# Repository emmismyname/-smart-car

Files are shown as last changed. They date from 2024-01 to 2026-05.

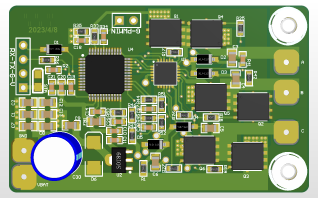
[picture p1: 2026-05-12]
hardware/ESC_Brushless_V4.12.png

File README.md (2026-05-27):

# Smart Car Project (Electromagnetic)

A high-speed intelligent vehicle based on the **STC32G** microcontroller, designed for electromagnetic field tracking competitions.

## 🚗 Overview
This project features an autonomous car that detects alternating magnetic fields from a track. It utilizes PID control for steering and speed management.

* **MCU**: STC32G12K128 (8051 Architecture)
* **Tools**: Altium Designer (Hardware), Keil uVision5 (Software)
* **Key Features**: Inductive sensing, PID control, Brushless ESC support.

---

## 🛠️ Hardware Design
The hardware files are located in the `/hardware` directory.

### 1. Driver Board
Handles signal processing from induction coils and controls the motors.

### 2. Power Module
Regulates 2S/3S LiPo battery input to stable 5V and 3.3V rails.



---

## 📂 Repository Structure
* `hardware/`: Altium Designer schematics and PCB layouts.
* `USER/`: Core application logic and interrupt handlers.
* `Libraries/`: Seekfree STC32 open-source library and drivers.
* `Docs/`: Pinout maps and sensor calibration data.

---

## 🚀 Getting Started
1.  **Hardware**: Open `.PcbDoc` files in Altium Designer to view layouts or generate Gerber files for manufacturing.
2.  **Software**:
    * Open the project in **Keil5**.
    * Compile and flash the firmware via STC-ISP.
    * Monitor sensor values using the serial debugger.

---

## 📈 Project Status
- [x] Power module design & testing
- [x] Driver board PCB layout
- [ ] PID algorithm optimization for high-speed cornering
- [ ] Integration of Brushless ESC

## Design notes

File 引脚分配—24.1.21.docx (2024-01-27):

一、主板 STC32F（核心板）

1、 主板运放通信 HS_SPI_2：

P25 SCLK_2 时钟信号

P24 MISO_2 从主传输

P23 MOSI_2 主从传输

P22 SS_2 片选信号

2、主板遥控板通信 UART_2：

P10 RxD2 串口接收端

P11 TxD2 串口发送端

2、 IMU姿态 HS_SPI_4：

P32 SCLK_4时钟信号

P33 MISO_4从主传输

P34 MOSI_4 主从传输

P35 SS_4 片选信号

4、无线串口UART_4：

P02 RxD4 串口发送端

P03 TxD4 串口接收端

P07 IO 无线串口RST

P45 IO 无线串口NC（悬空）

5、编码器1 T3：

P04 T3 定时器外部输入

P53 IO 编码器方向

6、编码器2 T4：

P06 T4 定时器外部输入

P00 IO 编码器方向

7、电池电压 ADC5：

P15 ADC4 模数转换

8、霍尔传感器 INT3：

P37 INT3 外部中断

9、电机信号 PWM：

P13 PWM2 PWM波形输出

P26 PWM4 PWM波形输出

P01 IO 电机方向

P05 IO 电机方向

10、蜂鸣器 IO：

P14 IO 蜂鸣器

11、按键 IO：

P50、P51、P16

12、复位 RST

P54 RST 复位键

（PCB Layout时为了连线方便GPIO可跟换连接引脚）

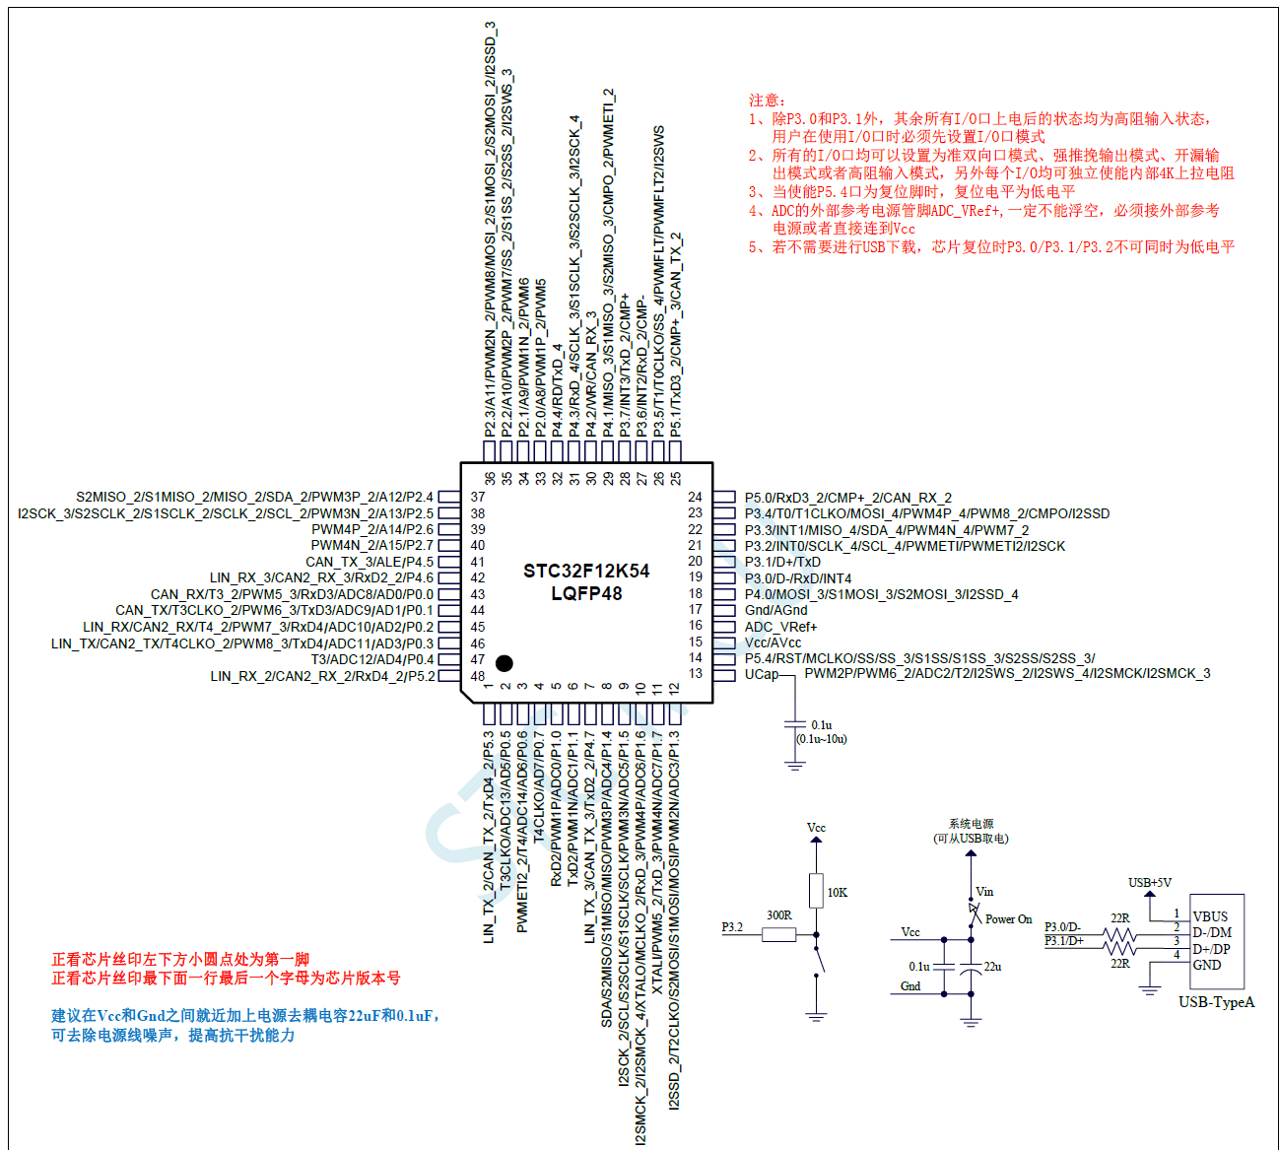
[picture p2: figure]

二、运放板 STC32F（贴片）

1.运放主板通信 HS_SPI_2：

P25 SCLK_2 时钟信号

P24 MISO_2 从主传输

P23 MOSI_2 主从传输

P22 SS_2 片选信号

2.TOF测距 模拟IIC：

P37 INT4 外部中断

P36 IO 使能引脚

P46 IO 模拟I2C_SDA

P47 IO 模拟I2C_SCL

3.运放 ADC：

P13--17 —>ADC3-7（5）

P00--06 —>ADC8-14（7）

4.烧录 ：

P30 D- 烧录接收端

P31 D+ 烧录发送端

5.复位：

P54 RST复位键

三、遥控板 STC32G（核心板）

1.遥控主板通信 UART_2：

P10 RxD2 串口接收端

P11 TxD2 串口发送端

2.OLED显示屏 SPI_2：

P25 SCLK_2 时钟信号

P24 MISO_2 从主传输

P23 MOSI_2 主从传输

P22 SS_2 片选信号

3.按键 IO（连线从简，布局优先）：

0-9数字按键（10P）

确认、返回（2P）

退格（1P）

点号（1P）

拨码（2P）

五向按键（5P）

4.复位：

P54 RST复位键

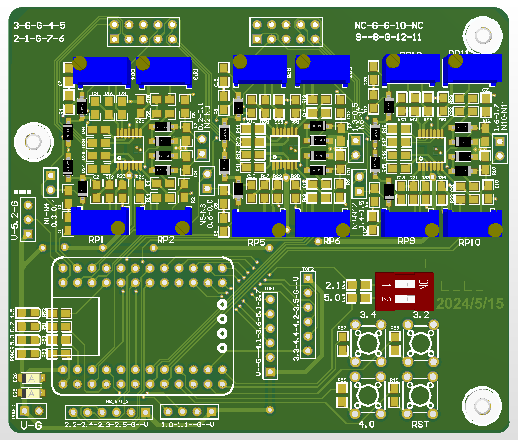
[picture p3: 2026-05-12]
hardware/12·channel amplifier.png

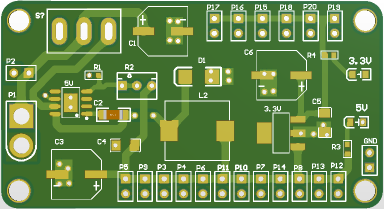
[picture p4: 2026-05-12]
hardware/Power_Module.png

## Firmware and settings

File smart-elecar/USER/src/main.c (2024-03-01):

/*********************************************************************************************************************
 * COPYRIGHT NOTICE
 * Copyright (c) 2020,逐飞科技
 * All rights reserved.
 * 技术讨论QQ群：一群：179029047(已满)  二群：244861897(已满)  三群：824575535
 *
 * 以下所有内容版权均属逐飞科技所有，未经允许不得用于商业用途，
 * 欢迎各位使用并传播本程序，修改内容时必须保留逐飞科技的版权声明。
 *
 * @file       		main
 * @company	   		成都逐飞科技有限公司
 * @author     		逐飞科技(QQ790875685)
 * @version    		查看doc内version文件 版本说明
 * @Software 		MDK FOR C251 V5.60
 * @Target core		STC32G12K128
 * @Taobao   		https://seekfree.taobao.com/
 * @date       		2020-12-18
 ********************************************************************************************************************/

#include "headfile.h"
#include "allcodeinr.h"

/*********************************************函数声明*********************************************************/

/********************************初始化操作函数**********/
void initall_PID();			// PID结构体内误差清理
void arangement_init(); // 初始化设定
void parameter_init();	// 初始化设定
/***************************************************************************************************/

/********************************运动模式操作函数**********/

void Hall_detection(); // 霍尔检测
void TOF_detection();	 // 红外检测
void left_infrared();	 // 左红外避障
void right_infrared(); // 右红外避障

/***************************************************************************************************/

/********************************电机输出和电磁电压检测操作函数**********/
void ADC_battery_quire(); // 获取电池的电压数值
/***************************************************************************************************/

/********************************显示屏操作函数**********/
void system_display(); // 根据按键反馈对应界面
/***************************************************************************************************/

/********************************电感函数**********/
void Element_Idef(); // 元素识别
/**************************************************/

/********************************PID相关函数**********/
void PID_all_set();
/****************************************************/
void start_dection(); // 发车检测
void stop_dection();	// 停车检测
/*
 * 系统频率，可查看board.h中的 FOSC 宏定义修改。
 * board.h文件中FOSC的值设置为0,则程序自动设置系统频率为33.1776MHZ
 * 在board_init中,已经将P54引脚设置为复位
 * 如果需要使用P54引脚,可以在board.c文件中的board_init()函数中删除SET_P54_RESRT即可
 */

void main()
{
	arangement_init(); // 初始化设定
	parameter_init();	 // 参数初始化
	while (1)
	{
		if (gyro_flag)
		{
			MPU_Acquire();
		}
		wireless_read(1);						 // 无线转串口入出
		system_display();						 // 显示界面
		Button_Scan();							 // 按钮扫描
		resetelec_Init();						 // 电感最大最小值检测
		wireless_send(uart_mode, 5); // 无线转串口输出
		start_dection();						 // 发车检测
		stop_dection();							 // 停车检测
	}
}

void start_dection() // 发车检测
{
	if (jiangxing_No_1.start_flag == 1)
	{
		switch (jiangxing_No_1.start_mode)
		{
		case 0:
		{
			jiangxing_No_1.stop_flag = 0; // 停车置零
			initall_PID();
			// 初始化读取积分零漂
			motor_flag = 0;
			gyro_flag = 1; //
			yaw_output = 0.0f;
			pitch = 0.0f;
			distance_L = 0;
			distance_R = 0;
			trace_flag=1;
			/////////////////////////////////////////
			// 显示屏开关关闭
			button_switch = 0;
			display_switch = 0;
			// 陀螺仪初始化
			motor_flag = 1;
			Target_speed = base_speed; // 速度控制
			//////////////////////
			jiangxing_No_1.start_flag = 0; // 清除标志位
			///////////////////////////////
		}
		break;
    case 1://距离跑
		{
  


		}
    break;

		default:
			break;
		}
	}
}

void stop_dection() // 停车检测
{
	if (jiangxing_No_1.stop_flag == 1) // 停车标志位为1
	{
		jiangxing_No_1.start_flag = 0; // 发车置零
		motor_flag = 0;
		trace_flag=0;
		jiangxing_No_1.stop_flag = 0;
	}
}

void arangement_init() // 初始化设定
{
	board_init(); // 初始化寄存器,勿删除此句代码。
	// 此处编写用户代码(例如：外设初始化代码等)
	iap_init();					// 初始化EEPROM
	ips114_init();			// 初始化1.1.4寸ips屏幕
	DisableGlobalIRQ(); // 关闭总中断
	sys_clk = 35000000; // 设置系统频率为35MHz
	WTST = 0;						// 设置程序代码等待参数，赋值为0可将CPU执行程序的速度设置为最快
	// sys_clk可选值:30000000, 27000000. 24000000, 22118400, 20000000, 18432000, 12000000, 11059200, 6000000, 5529600。
	// 设置系统频率，此频率需要跟STC-ISP软件中的 <输入用户程序运行的IRC频率>选项的频率一致。
	// 如果频率设置不对，将会导致串口的数据不正常,PWM的工作不正常等等。
	board_init(); // 设置玩主频后再次初始化内部寄存器
	delay_init();
	ips114_init();														// 初始化1.1.4寸ips屏幕
	wireless_uart_init();											// 无线转串口模块初始化
	ctimer_count_init(SPEEDL_PLUSE);					// 初始化定时器0作为外部计数
	ctimer_count_init(SPEEDR_PLUSE);					// 初始化定时器3作为外部计数
	gpio_mode(KEY1_PIN, GPI_IMPEDANCE);				// S1按键引脚模式: 高阻输出
	gpio_mode(KEY2_PIN, GPI_IMPEDANCE);				// S2按键引脚模式: 高阻输出
	gpio_mode(KEY3_PIN, GPI_IMPEDANCE);				// S3按键引脚模式: 高阻输出
	gpio_mode(KEY4_PIN, GPI_IMPEDANCE);				// S4按键引脚模式: 高阻输出
	gpio_mode(HRTRIG, GPI_IMPEDANCE);					// S4按键引脚模式: 高阻输出
	gpio_mode(P6_7, GPO_PP);									// 将P6.7蜂鸣器设置为推挽输出
	BEEP = 0;																	// 蜂鸣器关闭
	pit_timer_ms(TIM_4, 5);										// 使用定时器4做周期中断，时间5ms一次。电机控制
	EnableGlobalIRQ();												// 开启总中断
	adc_init(BAT_VOL_PIN, ADC_SYSclk_DIV_32); // 初始化电压引脚
	initall_PID();														// PID结构体清零
	gpio_mode(P6_4, GPO_PP);									// P64引脚设置为推挽输出
	gpio_mode(P6_0, GPO_PP);									// P60引脚设置为推挽输出
	pwm_init(PWM_1, 17000, 0);								// 初始化PWM1  使用P60引脚  初始化频率为17Khz
	pwm_init(PWM_2, 17000, 0);								// 初始化PWM2  使用P62引脚  初始化频率为17Khz
	adc_init(ADC_P00, 0);											// P00引脚		具体通道与引脚对应关系可以查看zf_adc.h文件	  adc[7].data_0 = adc_mean_filter(ADC_P00,8);		//采集并处理ADC_P16电压，精度12位R1—————(L1)
	adc_init(ADC_P01, 0);											// P01引脚		具体通道与引脚对应关系可以查看zf_adc.h文件	  adc[6].data_0 = adc_mean_filter(ADC_P01,8);		//采集并处理ADC_P14电压，精度12位R2—————(L2)
	adc_init(ADC_P05, 0);											// P05引脚		具体通道与引脚对应关系可以查看zf_adc.h文件	  adc[5].data_0 = adc_mean_filter(ADC_P06,8);		//采集并处理ADC_P06电压，精度12位R3—————(L3)
	adc_init(ADC_P13, 0);											// P13引脚		具体通道与引脚对应关系可以查看zf_adc.h文件		adc[1].data_0 = adc_mean_filter(ADC_P13,8);		//采集并处理ADC_P17电压，精度12位L1—————(L7)
	adc_init(ADC_P14, 0);											// P14引脚		具体通道与引脚对应关系可以查看zf_adc.h文件    adc[2].data_0 = adc_mean_filter(ADC_P14,8);		//采集并处理ADC_P13电压，精度12位L2—————(L6)
	adc_init(ADC_P16, 0);											// P16引脚		具体通道与引脚对应关系可以查看zf_adc.h文件    adc[3].data_0 = adc_mean_filter(ADC_P16,8);		//采集并处理ADC_P01电压，精度12位L3—————(L5)
	adc_init(ADC_P17, 0);											// P17引脚		具体通道与引脚对应关系可以查看zf_adc.h文件	  adc[4].data_0 = adc_mean_filter(ADC_P17,8);		//采集并处理ADC_P05电压，精度12位M-—————(L4)
	adc_init(ADC_P06, 0);											// P06引脚		具体通道与引脚对应关系可以查看zf_adc.h文件
	adc_init(ADC_P10, 0);											// P10引脚
	adc_init(ADC_P11, 0);											// P11引脚
	// 外部中断2，3打开
	exit_init(INT2_P36, FALLING_EDGE);
	exit_init(INT3_P37, FALLING_EDGE);
	// EX2=1;
	// tof initial
	//	while (dl1a_init())
	//	{
	//		delay_ms(500);
	//		printf("VL53L0X init try again.\r\n");
	//	}

	while (MPU_Init())
	{
		printf("STC32 MPU6050 GYRO Init test!  \r\n");
	}
	MPU6050_DMP_Init();
	printf("STC32 MPU6050 DMP test!  \r\n");

	read_all_par(); // 读取eeprom数值
									// Zero_Offset_set(); // mpu6050 DMP上电矫正时间
}

void parameter_init() // 参数初始化
{
	// 后排电感最大值
	adc[1].data_max = 2262;
	adc[2].data_max = 2307;
	adc[3].data_max = 2038;
	adc[4].data_max = 2282;
	adc[5].data_max = 2081;
	// 前排电感最大值
	adc[6].data_max = 2146;
	adc[7].data_max = 2113;
	adc[8].data_max = 2022;
	adc[9].data_max = 2051;
	adc[10].data_max = 2030;
	// 后排电感最小值
	adc[1].data_min = 0;
	adc[2].data_min = 0;
	adc[3].data_min = 0;
	adc[4].data_min = 0;
	adc[5].data_min = 0;
	// 前排电感最小值
	adc[6].data_min = 0;
	adc[7].data_min = 0;
	adc[8].data_min = 0;
	adc[9].data_min = 0;
	adc[10].data_min = 0;
	// ZeroOffset_init(); //yaw数值零飘
	// 显示屏页面设置
	sys_display[1] = 1;
	sys_display[2] = 0;
	sys_display[3] = 0;
	button_switch = 1;	// 按钮开启
	display_switch = 1; // 显示开启
	gyro_flag = 1;			// 开启陀螺仪
	yaw_output = 0.0f;
	// PID结构体清零
	initall_PID();
	// 初始化读取积分零漂
	motor_flag = 0;// 电机软开关关闭

	distance_L = 0; // 左轮里程清0
	distance_R = 0;			// 右轮里程清0

	//////////////////////
	jiangxing_No_1.start_flag = 0; // 清除标志位
	jiangxing_No_1.stop_flag = 1;	 // 清除标志位
	jiangxing_No_1.start_mode = 0; // 发车模式
	base_speed = 120;							 // 速度控制
}

//-------------------------------------------------------------------------------------------------------------------
// @brief		PID结构体内容清理
//
//-------------------------------------------------------------------------------------------------------------------
void initall_PID()
{
	pid_init(&Speed_PID_L);
	pid_init(&Speed_PID_R);
	pid_init(&Swerve_PID);
	pid_init(&Forward_PID);
	pid_init(&Pout_PID);
	pid_init(&Pout_rate_PID);
	pid_init(&roundaboutL_PID);
	pid_init(&roundaboutR_PID);
	pid_init(&climb_PID);
	// pid_init(&fuzzy_PID);
	err = 0;
	err_last = 0;
	err_angle_rate = 0;
}

//-------------------------------------------------------------------------------------------------------------------
//  @brief      按钮获取
//  @param      按键状态
//  @param      拨码状态
//  @return     PID参数调整 显示界面
//-------------------------------------------------------------------------------------------------------------------
void Button_Scan()
{
	// 获取拨码开关状态
	sw1_status = SW1_PIN;
	sw2_status = SW2_PIN;

	// 使用此方法优点在于，不需要使用while(1) 等待，避免处理器资源浪费
	// 保存按键状态
	key1_last_status = key1_status;
	key2_last_status = key2_status;
	key3_last_status = key3_status;
	key4_last_status = key4_status;
	// 读取当前按键状态
	key1_status = KEY1_PIN;
	key2_status = KEY2_PIN;
	key3_status = KEY3_PIN;
	key4_status = KEY4_PIN;

	// 检测到按键按下之后  并放开置位标志位
	if (key1_status && !key1_last_status)
		key1_flag = 1;
	if (key2_status && !key2_last_status)
		key2_flag = 1;
	if (key3_status && !key3_last_status)
		key3_flag = 1;
	if (key4_status && !key4_last_status)
		key4_flag = 1;

	// 标志位置位之后，可以使用标志位执行自己想要做的事件
	if (key1_flag)
	{
		if (sw1_status == 1 && sw2_status == 1)
		{
			cursor = cursor - 1;
			ips114_clear(WHITE);											// 清屏
			ips114_showstr(0, cursor, (uint8 *)"->"); // 光标位置
		}
		///////////////使用按键之后，应该清除标志位
		key1_flag = 0;													// 使用按键之后，应该清除标志位
		if (sw1_status == 0 && sw2_status == 0) // 双拨码开关屏幕
		{
			ips114_clear(WHITE); // 清屏
			display_switch = 0;
			button_switch = 0;
		}
	}
	if (key2_flag)
	{
		if (sw1_status == 1 && sw2_status == 1)
		{
			cursor = cursor + 1;
			ips114_clear(WHITE);											// 清屏
			ips114_showstr(0, cursor, (uint8 *)"->"); // 光标位置
		}
		///////////////使用按键之后，应该清除标志位
		key2_flag = 0;													// 使用按键之后，应该清除标志位
		if (sw1_status == 0 && sw2_status == 0) // 双拨码开关屏幕
		{
			display_switch = 1;
			button_switch = 1;
		}
	}

	if (button_switch == 1) // debug打开按键调参
	{
		if (key3_flag)
		{
			if (sw1_status == 1 && sw2_status == 1) // 光标操作
			{
				if (sys_display[1] == 1)
				{
					sys_display[1] = cursor + 2;
				}
				else if (sys_display[1] != 1)
				{
					sys_display[2] = cursor + 1;
				}
				ips114_clear(WHITE);
				cursor = 0;
				ips114_showstr(0, cursor, (uint8 *)"->"); // 光标位置
			}

			else if ((sw2_status == 0 || sw1_status == 0) && sys_display[1] == 2) // 软件打开电机占控比输出
			{
				switch (cursor)
				{
				case 0:
					jiangxing_No_1.start_flag = 1;
					break;
				case 1:
					resetelec_flag = 0;
					break;
				case 2:
					PID_all_set(); // 设置pid
					break;
				case 3:
				{
					uart_mode = uart_mode + 1;
					if (uart_mode > 10)
						uart_mode = 10;
					else if (uart_mode < 0)
						uart_mode = 0;
				}
				break;
				case 4:
				{
					brusheless_flag = 1;
					brusheless_duty = 630;
					delay_ms(1000);
					trace_flag = 1;
					initall_PID();
				}
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

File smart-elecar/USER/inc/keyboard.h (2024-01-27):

#ifndef _KEY_BOARD_H_
#define _KEY_BOARD_H_

#define KEY1_PIN P73
#define KEY2_PIN P71
#define KEY3_PIN P72
#define KEY4_PIN P70
// 定义拨码开关引脚
#define SW1_PIN P75
#define SW2_PIN P76

#include "common.h"

// 拨码开关状态变量
extern uint8 sw1_status;
extern uint8 sw2_status;

// 开关状态变量
extern uint8 key1_status;
extern uint8 key2_status;
extern uint8 key3_status;
extern uint8 key4_status;

// 上一次开关状态变量
extern uint8 key1_last_status;
extern uint8 key2_last_status;
extern uint8 key3_last_status;
extern uint8 key4_last_status;

// 开关标志位
extern uint8 key1_flag;
extern uint8 key2_flag;
extern uint8 key3_flag;
extern uint8 key4_flag;

extern int button_switch; // 第三和第四个按键的开关，调参开关开关与否

extern void Button_Scan();

#endif

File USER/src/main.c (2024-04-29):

/*********************************************************************************************************************
 * COPYRIGHT NOTICE
 * Copyright (c) 2020,逐飞科技
 * All rights reserved.
 * 技术讨论QQ群：一群：179029047(已满)  二群：244861897(已满)  三群：824575535
 *
 * 以下所有内容版权均属逐飞科技所有，未经允许不得用于商业用途，
 * 欢迎各位使用并传播本程序，修改内容时必须保留逐飞科技的版权声明。
 *
 * @file       		main
 * @company	   		成都逐飞科技有限公司
 * @author     		逐飞科技(QQ790875685)
 * @version    		查看doc内version文件 版本说明
 * @Software 		MDK FOR C251 V5.60
 * @Target core		STC32
 * @Taobao   		https://seekfree.taobao.com/
 * @date       		2023-07-27

 ********************************************************************************************************************/
#include "headfile.h"
#include "mycode.h"


// 关于内核频率的设定，可以查看board.h文件
// 在board_init中,已经将P54引脚设置为复位
// 如果需要使用P54引脚,可以在board.c文件中的board_init()函数中删除SET_P54_RESRT即可


void main()
{ 
		//板载初始化·引脚			
		// 此处编写用户代码 例如外设初始化代码等
		EAXFR=1;//使能访问XFR
		clock_init(SYSTEM_CLOCK_52M);	// 初始化系统频率,勿删除此句代码。
		board_init();					// 初始化寄存器,勿删除此句代码。
		DisableGlobalIRQ(); // 	关闭所有中断

		ctimer_count_init(SPEEDR_PLUSE);					// 初始化定时器4作为外部计数
		ctimer_count_init(SPEEDL_PLUSE);					// 初始化定时器3作为外部计数
		pit_timer_ms(TIM_1, 5);				// 使用定时器4做周期中断，时间4ms一次。电机控制

    LED_init();//led初始化
		WORK_LED_on();//工作灯打开
		Disablespiwork();// 关闭SPI工作内容


		spi_slave_init();							// 初始化SPI(作为从机)		
		wireless_uart_init();				  // 无线转串口模块初始化
	
		motor_init();
		switch_init();                //按键初始化
		iap_init();			            	// 初始化EEPROM
		EnableSPIIRQ();								// 使能SPI中断
		EnableGlobalIRQ();						// 使能总中断


	  pid_all_init();//初始化
		disenablemotor();//关闭电机
		

		while (MPU_Init())
		{
			printf("STC32 MPU6050 GYRO Init test!  \r\n");
		}
		MPU6050_DMP_Init();
		printf("STC32 MPU6050 DMP test!  \r\n");
	  delay_ms(20);//等待定时器获取初始化的时候的编码数值
	  get_switch();//获取初始化时候的拨码状态，用于判断是否要读取eeprom的数值
		
		if(SWITCH3_FLAG==1)
		{
			 car_init(&jiangxing_No_1);//车状态初始化
			 delay_ms(100);
       read_all_par();
			 delay_ms(100);
		}
		else
		{
			  car_init(&jiangxing_No_1);//车状态初始化
				Speed_PID_L.KP=33.0f;
				Speed_PID_L.KI=3.4f;
				Speed_PID_L.KD=0.0f;	
				Speed_PID_R.KP=33.0f;
				Speed_PID_R.KI=3.4f;
				Speed_PID_R.KD=0.0f;
				Forward_PID.KP=-3;
				Forward_PID.KI=-0.01;
				Forward_PID.KD=-40;
				gyro_d=0.01;
		}
   
    Zero_Offset_set();  //处理零飘
		Enablespiwork();   //开启工作
//		enablemotor();//使能电机
	 // 此处编写用户代码 例如外设初始化代码等


    while(1)	
    { 

			MPU_Acquire();			
			wireless_read(1);
			wireless_send(jiangxing_No_1.uart_mode, 5);
		  printf("%d,%d,%d,%d,%d ,%d,%f\n",SWITCH1_FLAG,SWITCH2_FLAG,SWITCH3_FLAG,SWITCH4_FLAG,jiangxing_No_1.uart_mode,uart_mode,Forward_PID.KP);
			printf("%f,%f,%f\n", y_gyro_offset, z_gyro_offset, x_gyro_offset);
        // 此处编写需要循环执行的代码
    }
}

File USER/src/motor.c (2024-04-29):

#include "motor.h"

uint8 brusheless_flag;	// 无刷开关
uint16 brusheless_duty; // 无刷电机数值数值范围在500-1000对应占空比为0%-100%
uint8 motor_flag;

uint8 Dir_L = 1;   // 1左边方向正转  0反转
uint8 Dir_R = 0;   // 0右边方向正转  1反转
uint8 Dir_car = 1; // 正走dir_car=1 L=1 R=0  ;dir_car=0 反走 L=0 R=1

int16 templ_pluse = 0;
int16 tempr_pluse = 0;

float Target_Speed_L = 0; // 左轮目标速度
float Target_Speed_R = 0; // 右轮目标速度

float Current_Speed_L; // 左轮当前速度
float Current_Speed_R; // 右轮当前速度

float duty_L;	  // 左电机pid占空比
float duty_R;	  // 右电机pid占空比
float set_duty_L; // 左电机输出占空比
float set_duty_R; // 右电机输出占空比

int32 distance_L = 0; // 左轮行驶距离
int32 distance_R = 0; // 右轮行驶距离

PID_P Swerve_PID;	   // 转弯差速pid
PID_P Forward_PID;	   // 直行PID控制
PID_P Pout_PID;		   // 陀螺仪PID控制
PID_P Pout_rate_PID; //角速度PID控制
PID_P roundaboutL_PID; // 左环岛pid
PID_P roundaboutR_PID; // 右环岛pid
PID_P Speed_PID_L;	   // 左轮速度pid
PID_P Speed_PID_R;	   // 右轮速度pid
PID_P climb_PID;				//上坡pid
int templ_pluse;	  // 左轮脉冲个数
int tempr_pluse;	  // 右轮脉冲个数
int Target_speed = 0; // 车体目标速度

// float PIDOUT_speed_L;			//左轮速度环的偏差计算结果
// float PIDOUT_speed_R;			//右轮速度环的偏差计算结果

// int32 Target_pluse_L=0;			//左轮目标脉冲数目
// int32 Target_pluse_R=0;			//右轮目标脉冲数目

// int32 Motor_pluse_L;			//左轮速度环的脉冲个数
// int32 Motor_pluse_R;			//左轮速度环的脉冲个数

// float Motor_duty_L=470;			//左电机目标初始占空比用于克服死区电压，电源为满电状态
// float Motor_duty_R=360;			//右电机目标初始占空比用于克服死区电压，电源为满电状态

void get_error(PID_P *pid,float senddata)
{
  pid->err=senddata;
}

void enablemotor()
{
	jiangxing_No_1.motor_flag=1;//电机软件开关
}

void disenablemotor()//电机软件失能
{
	jiangxing_No_1.motor_flag=0;//电机软件开关
}

//-------------------------------------------------------------------------------------------------------------------
//  @brief      pid控制器输出更新内部
//  @param      pid				pid参数
//  @param
//  @return     *pid参数 内部输出结果清零
//-------------------------------------------------------------------------------------------------------------------
void pid_init(PID_P *pid) // PID的误差输出初始化
{
	pid->last_err = 0;
	pid->lastBefore_err = 0;
	pid->err = 0;
	pid->pid_out = 0;
	pid->i_out = 0;
	pid->d_out = 0;
	pid->p_out = 0;
}

//-------------------------------------------------------------------------------------------------------------------
//  @brief    	PID的全部初始化
//  @param      none
//  @param
//  @return     PID的全部初始化
//-------------------------------------------------------------------------------------------------------------------
void pid_all_init() // PID的全部初始化
{
	pid_init(&Speed_PID_L);
	pid_init(&Speed_PID_R);
	pid_init(&Forward_PID);
	pid_init(&Swerve_PID);
	
}

//-------------------------------------------------------------------------------------------------------------------
//  @brief      pid位置式控制器输出
//  @param      pid				pid参数
//  @param      error			pid输入误差
//  @return     PID输出结果
//-------------------------------------------------------------------------------------------------------------------
float PID_Loc_Control(PID_P *pid, float error)
{
	if (error > 5 || error < -5)
	{
		pid->i_out += pid->KI * error;
	} // 位置式PID积分项累加
	else if (error <= 5 || error >= -5)
	{
		pid->i_out = 0;
	}
	pid->p_out = pid->KP * error;
	pid->d_out = pid->KD * (error - pid->last_err);
	pid->pid_out = pid->i_out + pid->p_out + pid->d_out;

	// PID输出限幅
	if (pid->pid_out > (600))
		pid->pid_out = 600;
	if (pid->pid_out < -(600))
		pid->pid_out = -(600);
	// 更新误差,用于下次计算
	pid->last_err = error;
	// 返回PID输出值
	return pid->pid_out;
}

//-------------------------------------------------------------------------------------------------------------------
//  @brief      pid位置式控制器输出
//  @param      pid				pid参数
//  @param      error			pid输入误差
//  @return     PID输出结果
//-------------------------------------------------------------------------------------------------------------------
float PID_Loc_direction_Control(PID_P *pid, float error)
{
	if (pid->err > 4 && pid->err < -4)
	{
		pid->i_out = 0;
	} // 位置式PID积分项累加
	else if (pid->err < 4 && pid->err > -4)
	{
		pid->i_out += pid->KI * error;
	}

	// pid->i_out += pid->KI * error;	   //位置式PID积分项累加

	if (pid->i_out > (100))
		pid->i_out = 100;
	if (pid->i_out < -(100))
		pid->i_out = -(100);
	pid->p_out = pid->KP * error;
	pid->d_out = pid->KD * (error - pid->last_err);
	pid->pid_out = pid->i_out + pid->p_out + pid->d_out;

	// PID输出限幅
	if (pid->pid_out > (600))
		pid->pid_out = 600;
	if (pid->pid_out < -(600))
		pid->pid_out = -(600);
	// 更新误差,用于下次计算
	pid->last_err = error;
	// 返回PID输出值
	return pid->pid_out;
}

//-------------------------------------------------------------------------------------------------------------------
//  @brief      pid位置式控制器输出
//  @param      pid				pid参数
//  @param      error			pid输入误差
//  @return     PID输出结果
//-------------------------------------------------------------------------------------------------------------------
float PID_Loc_angle_Control(PID_P *pid, float error)
{
	if (pid->err > 4 && pid->err < -4)
	{
		pid->i_out = 0;
	} // 位置式PID积分项累加
	else if (pid->err < 5 && pid->err > -5)
	{
		pid->i_out += pid->KI * error;
	}

	// pid->i_out += pid->KI * error;	   //位置式PID积分项累加

	if (pid->i_out > (1000))
		pid->i_out = 1000;
	if (pid->i_out < -(1000))
		pid->i_out = -(1000);
	pid->p_out = pid->KP * error;
	pid->d_out = pid->KD * (error - pid->last_err);
	pid->pid_out = pid->i_out + pid->p_out + pid->d_out;

	// PID输出限幅
	if (pid->pid_out > (100000))
		pid->pid_out = 100000;
	if (pid->pid_out < -(100000))
		pid->pid_out = -(100000);
	// 更新误差,用于下次计算
	pid->last_err = error;
	// 返回PID输出值
	return pid->pid_out;
}

//-------------------------------------------------------------------------------------------------------------------
//  @brief      pid位置式控制器输出
//  @param      pid				pid参数
//  @param      error			pid输入误差
//  @return     PID输出结果
//-------------------------------------------------------------------------------------------------------------------
float PID_Loc_angle_rate_Control(PID_P *pid, float error)
{
	if (pid->err > 10 && pid->err < -10)
	{
		pid->i_out = 0;
	} // 位置式PID积分项累加
	else if (pid->err < 10 && pid->err > -10)
	{
		pid->i_out += pid->KI * error;
	}

	// pid->i_out += pid->KI * error;	   //位置式PID积分项累加

	if (pid->i_out > (200))
		pid->i_out = 200;
	if (pid->i_out < -(200))
		pid->i_out = -(200);
	pid->p_out = pid->KP * error;
	pid->d_out = pid->KD * (error - pid->last_err);
	pid->pid_out = pid->i_out + pid->p_out + pid->d_out;

	// PID输出限幅
	if (pid->pid_out > (600))
		pid->pid_out = 600;
	if (pid->pid_out < -(600))
		pid->pid_out = -(600);
	// 更新误差,用于下次计算
	pid->last_err = error;
	// 返回PID输出值
	return pid->pid_out;
}
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

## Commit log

2024-01-27 Create smart-elecar
    程序内容
2026-05-12 Update driver board files
    [Driver_Board.SchDoc, Driver_Board2.28.PcbDoc]
2026-05-12 amplifier module
    [12·channel amplifier.PcbDoc]
2026-05-12 power module
    [Power_Module.PcbDoc]

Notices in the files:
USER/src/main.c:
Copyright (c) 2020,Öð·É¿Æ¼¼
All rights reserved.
